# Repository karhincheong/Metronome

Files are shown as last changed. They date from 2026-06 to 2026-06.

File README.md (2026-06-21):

# Metronome

An electronic metronome powered by an ESP32-S3-WROOM Module, utilising a 160 x 128 LCD-TFT screen and a speaker

## Motivation

I find my phone too distracting when attending music class, hence I'm making this metronome on a separate device so that its simple and non-distracting

## BOM

### Components

| Item | Description | Quantity | Unit Price (USD) | Total Price (USD) | URL | MOQ |
| --- | --- | --- | --- | --- | --- | --- |
| Capacitors | 0805 22 uF | 1 | 0.0696 | 0.7 | https://www.lcsc.com/product-detail/C5674.html | 10  |
| | 0805 4.7 uF | 2 | 0.0267 | 0.53 | https://www.lcsc.com/product-detail/C1779.html | 20  |
| | 0805 10 uF | 1 | 0.0421 | 0.84 | https://www.lcsc.com/product-detail/C17024.html | 20  |
| | 0805 0.1 uF | 2 | 0.0061 | 0.15 | https://www.lcsc.com/product-detail/C476766.html | 25  |
| LEDs | 0805 YELLOW | 1 | 0.0118 | 0.59 | https://www.lcsc.com/product-detail/C20608785.html | 50  |
| | 0805 BLUE | 1 | 0.0078 | 0.78 | https://www.lcsc.com/product-detail/C19171391.html | 100 |
| | 0805 GREEN | 1 | 0.0222 | 0.67 | https://www.lcsc.com/product-detail/C84260.html | 30  |
| | 0805 RED | 1 | 0.007 | 0.7 | https://www.lcsc.com/product-detail/C965812.html | 100 |
| JST Connector | | 1 | 0.0393 | 0.79 | https://www.lcsc.com/product-detail/C173752.html | 20  |
| USB-C Receptacle | | 1 | 0.0877 | 0.44 | https://www.lcsc.com/product-detail/C2988369.html  | 5 |
| TFT-LCD | ST7735 160\*128  | 1 | 3.2069 | 3.21 | https://www.lcsc.com/product-detail/C5329585.html  | 1 |
| Speaker | | 1 | 0.818 | 0.82 | https://www.lcsc.com/product-detail/C530531.html | 1 |
| Resistors | 0805 2k | 2 | 0.0031 | 0.31 | https://www.lcsc.com/product-detail/C2907248.html  | 100 |
| | 0805 10k | 4 | 0.0031 | 0.31 | https://www.lcsc.com/product-detail/C2930231.html  | 100 |
| | 0805 5.1k | 2 | 0.0028 | 0.28 | https://www.lcsc.com/product-detail/C27834.html | 100 |
| | 0805 330k | 1 | 0.004 | 0.4 | https://www.lcsc.com/product-detail/C114528.html | 100 |
| | 0805 15k | 1 | 0.0033 | 0.33 | https://www.lcsc.com/product-detail/C2930170.html  | 100 |
| | 0805 470Ω | 3 | 0.003 | 0.3 | https://www.lcsc.com/product-detail/C2907267.html  | 100 |
| Rotary Encoders  | EC11 | 3 | 1.9069 | 5.72 | https://www.lcsc.com/product-detail/C470742.html | 1 |
| Slide Switch | SPST | 1 | 0.0541 | 0.54 | https://www.lcsc.com/product-detail/C7498220.html  | 10  |
| Push Buttons | 4.5 x 4.5 mm | 2 | 0.0109 | 0.55 | https://www.lcsc.com/product-detail/C52092029.html | 50  |
| | ⌀ 10 mm | 1 | 0.3832 | 0.38 | https://www.lcsc.com/product-detail/C268254.html | 1 |
| Thermistor | NTC 10k | 1 | 0.685 | 0.69 | https://www.lcsc.com/product-detail/C17376775.html | 1 |
| ESP32-S3-WROOM-1 | | 1 | 4.5417 | 4.54 | https://www.lcsc.com/product-detail/C2913197.html  | 1 |
| MCP73871 | | 1 | 4.5329 | 4.53 | https://www.lcsc.com/product-detail/C5121473.html  | 1 |
| AMS1117 | 3.3V Variant | 1 | 0.0424 | 0.04 | https://www.lcsc.com/product-detail/C347222.html | 1 |
| MAX98357A | | 1 | 1.3362 | 1.34 | https://www.lcsc.com/product-detail/C910544.html | 1 |
| USBLC6-2SC6 | | 1 | 0.164 | 0.82 | https://www.lcsc.com/product-detail/C7519.html | 5 |
| Battery | 3.7V LiPO 300mAh | 1 | 0.79 | 0.79 | https://item.szlcsc.com/mro/419942.html | 1 |
| | | | | | | |
| TOTAL | | | | 32.09 | | |

### Other Costs Incurred

| Item | Description | Price |
| --- | --- | ----- |
| PCB Printing | JLCPCB | 2.00  |
| Shipping | UPS Express Saver | 9.24  |

## Assembly Instructions

| Folder | Description |
| --- | --- |
| `kicad/` | KiCAD files |
| `3d/` | 3D files for the case and the PCB |
| `src/` | Source Code for firmware |
| `production/` | Files for manufacturers |

1. Solder the components by hand onto the PCB. You may opt for PCBA for some of the components but it's expensive.
2. Flash firmware in `src/main` onto the PCB by connecting your computer to the USB-C on the PCB. You may also have to press down on BOOT and RESET for it to enter serial download mode
3. 3D Print the case of the the PCB.
4. Install the PCB into the case by screwing the PCB down using 4 M2 screws onto the 4 holes.

## Schematic Diagram

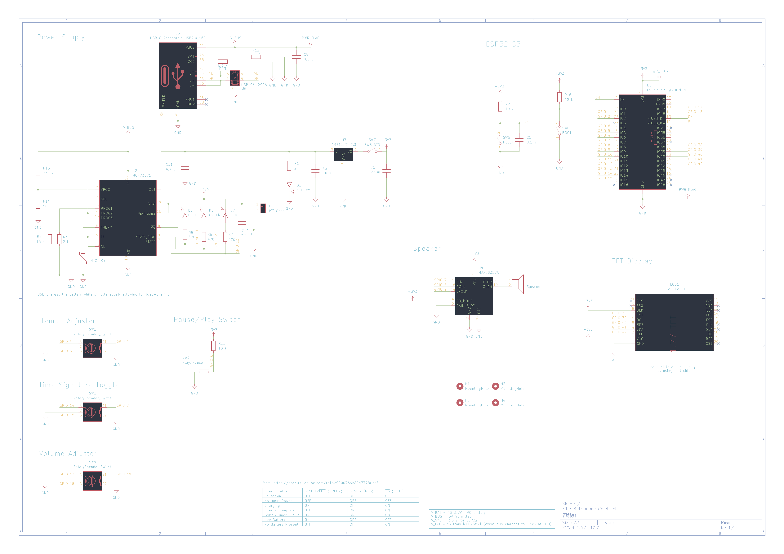
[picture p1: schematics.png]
Schematics


For clearer version, please refer `schematics.pdf`, or maybe you're trying to attract bugs ...

## PCB Layout

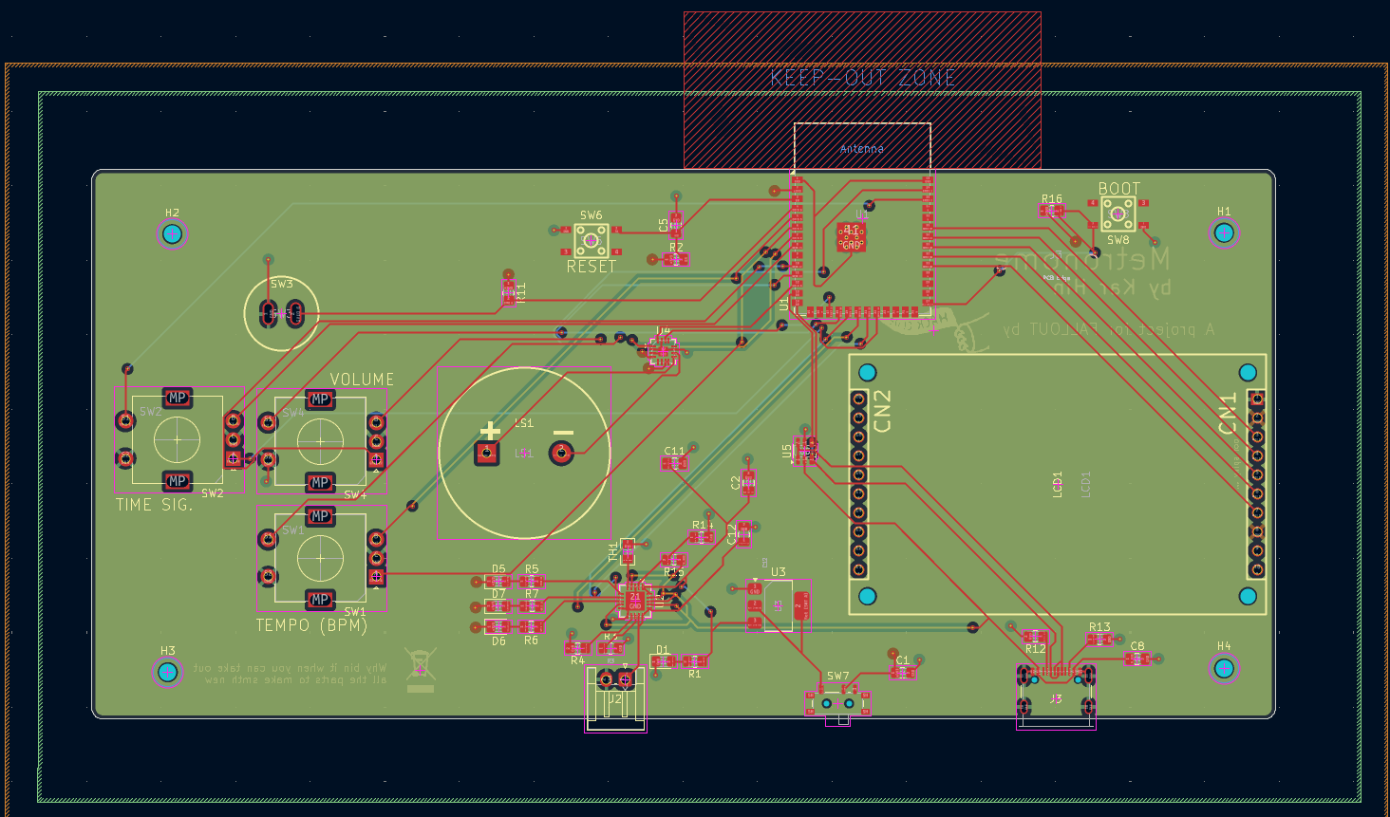
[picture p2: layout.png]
Layout


## PCB Render

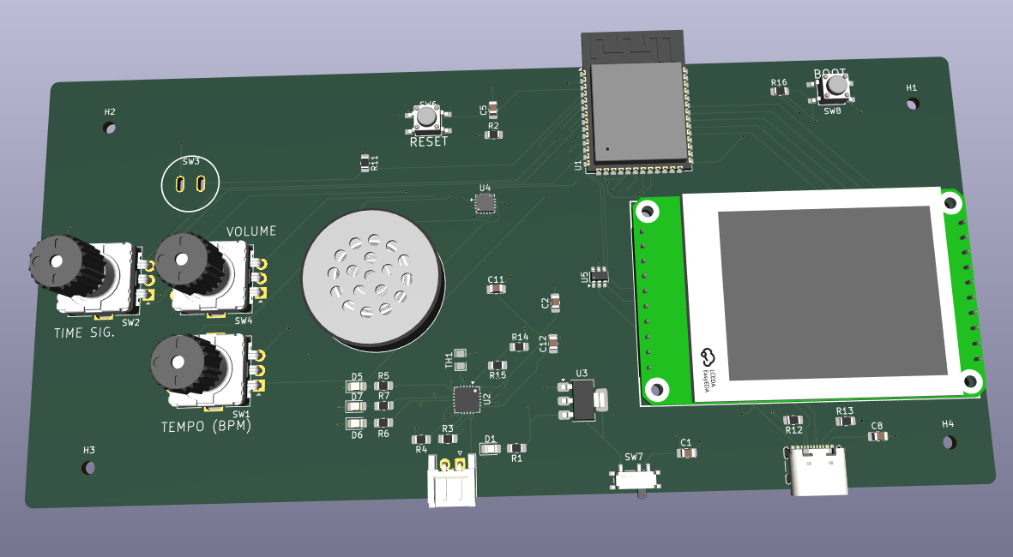
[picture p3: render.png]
PCB Render


You may refer to `3d/pcb3d.step` but note that there will not be any silkscreen or solder mask on it

## Case

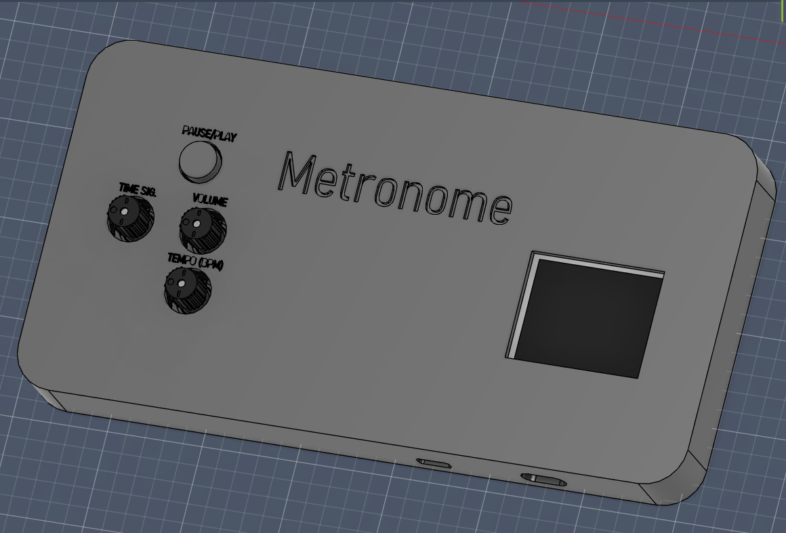
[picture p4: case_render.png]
Case Render


Refer to `3d/metronomecase.step` or `3d/metronomecase.f3d` if you use Autodesk Fusion

## Project Zine

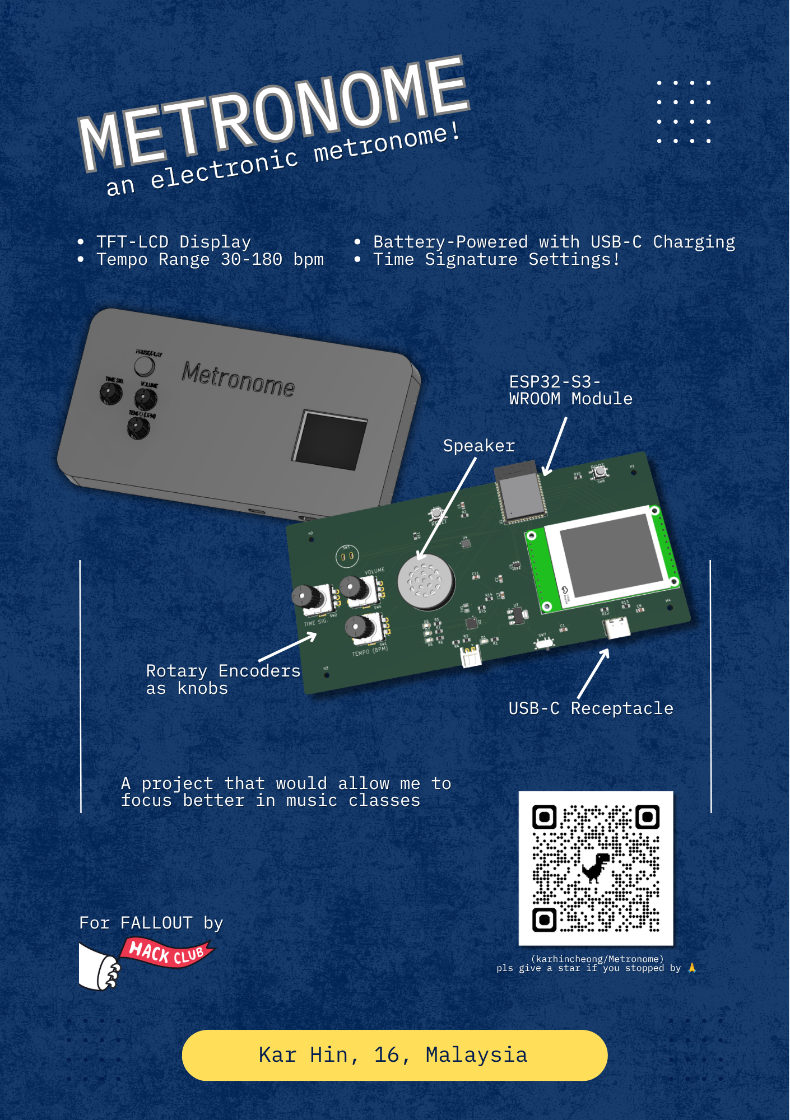
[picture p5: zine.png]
Zine


Uncompressed version at `zine.pdf`

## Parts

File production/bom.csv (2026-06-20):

Designator | Footprint | Quantity | Value | LCSC Part #
C1 | 0805 | 1 | 22 uF
C11, C12 | 0805 | 2 | 4.7 uF
C2 | 0805 | 1 | 10 uF
C5, C8 | 0805 | 2 | 0.1 uF
D1 | 0805 | 1 | YELLOW
D5 | 0805 | 1 | BLUE
D6 | 0805 | 1 | GREEN
D7 | 0805 | 1 | RED
J2 | JST_EH_S2B-EH_1x02_P2.50mm_Horizontal | 1 | JST Connector
J3 | USB_C_Receptacle_GCT_USB4105-xx-A_16P_TopMnt_Horizontal | 1 | USB_C_Receptacle_USB2.0_16P
LCD1 | LCD-TH_L56.0-W35.0-P2.54_HS180S10B | 1 | HS180S10B | C5329585
LS1 | SPK-TH_BD23.0-P10.00-D0.8-L-RD | 1 | Speaker
R1, R3 | 0805 | 2 | 2 k
R11, R14, R16, R2 | 0805 | 4 | 10 k
R12, R13 | 0805 | 2 | 5.1 k
R15 | 0805 | 1 | 330 k
R4 | 0805 | 1 | 15 k
R5, R6, R7 | 0805 | 3 | 470
SW1, SW2, SW4 | RotaryEncoder_Alps_EC11E-Switch_Vertical_H20mm | 3 | RotaryEncoder_Switch
SW3 | CONN-TH_PB-05B-R | 1 | Play/Pause
SW6 | SW-SMD_4P-L4.5-W4.5-P3.00-LS7.0_TS-1009S-03826 | 1 | RESET
SW7 | SW_SPDT_Shouhan_MSK12C02 | 1 | PWR_BTN
SW8 | SW-SMD_4P-L4.5-W4.5-P3.00-LS7.0_TS-1009S-03826 | 1 | BOOT
TH1 | R0805 | 1 | NTC 10k
U1 | ESP32-S3-WROOM-1 | 1 | ESP32-S3-WROOM-1
U2 | QFN-20-1EP_4x4mm_P0.5mm_EP2.5x2.5mm | 1 | MCP73871
U3 | SOT-223-3_TabPin2 | 1 | AMS1117-3.3
U4 | TQFN-16-1EP_3x3mm_P0.5mm_EP1.23x1.23mm | 1 | MAX98357A
U5 | SOT-23-6 | 1 | USBLC6-2SC6

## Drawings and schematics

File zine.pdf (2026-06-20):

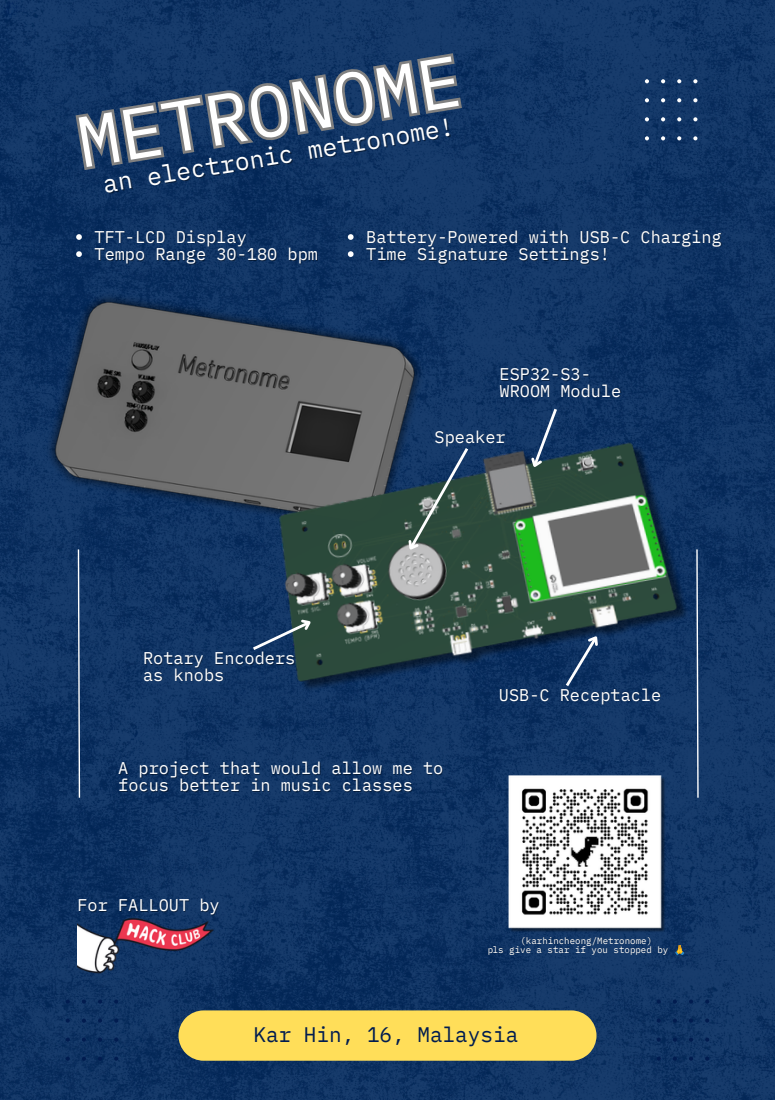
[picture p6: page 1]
Rotary Encoders as knobs; Speaker; USB-C Receptacle; ESP32-S3- WROOM Module

METRONOME METRONOME METRONOME

an electronic metronome!

TFT-LCD Display
Tempo Range 30-180 bpm

Battery-Powered with USB-C Charging
Time Signature Settings!

A project that would allow me to
focus better in music classes

For FALLOUT by

(karhincheong/Metronome)
pls give a star if you stopped by 🙏

Kar Hin, 16, Malaysia

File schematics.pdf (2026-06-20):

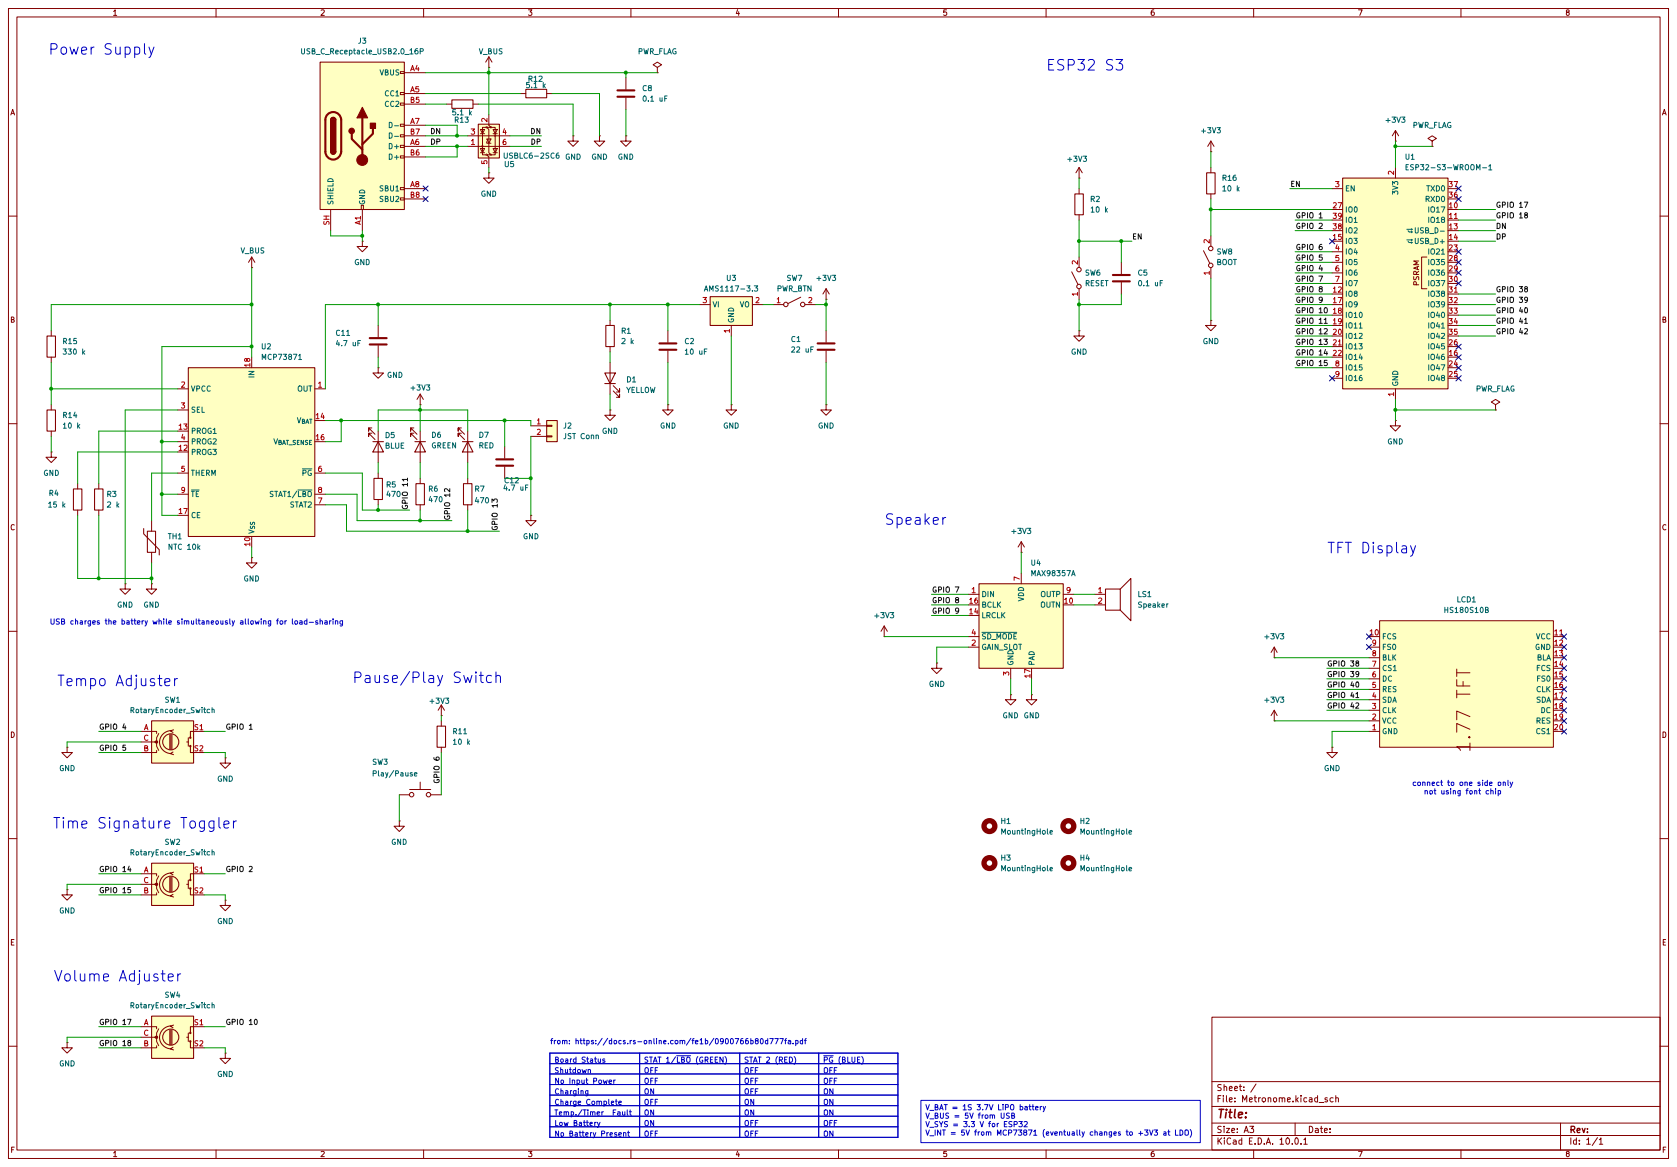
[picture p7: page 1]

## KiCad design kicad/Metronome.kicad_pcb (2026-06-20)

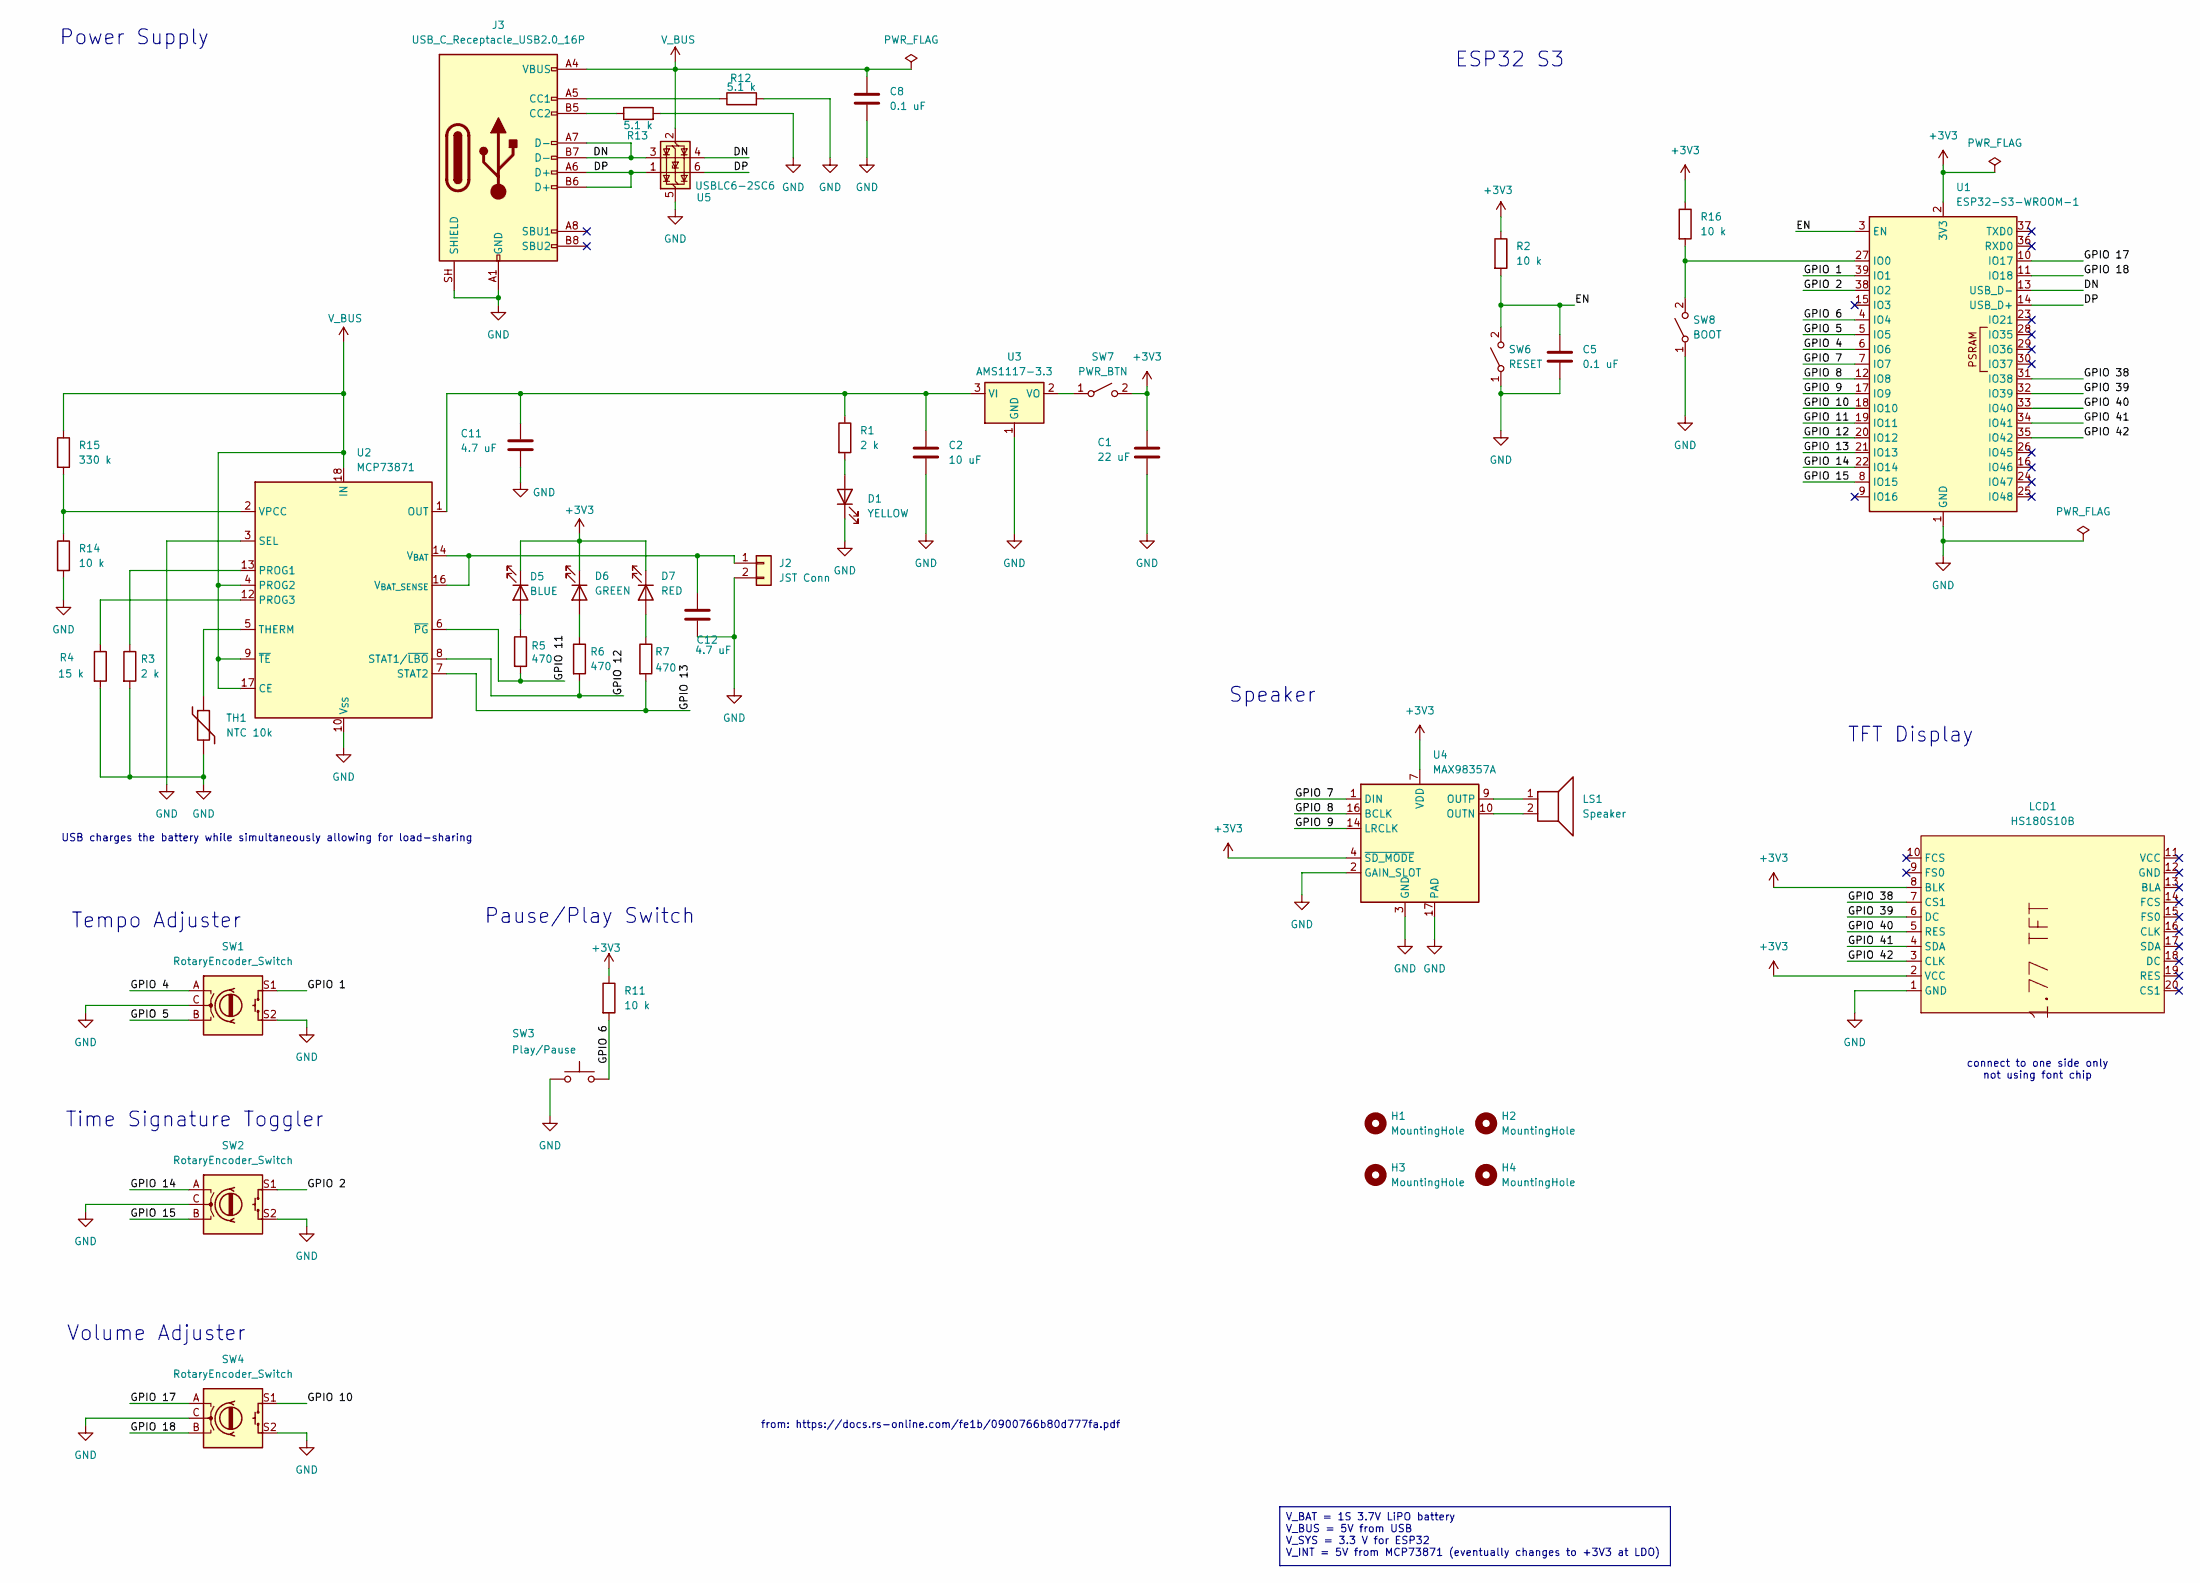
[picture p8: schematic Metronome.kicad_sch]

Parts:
C1: 22 uF; C_0805_2012Metric_Pad1.18x1.45mm_HandSolder
C2: 10 uF; C_0805_2012Metric_Pad1.18x1.45mm_HandSolder
C5, C8: 0.1 uF; C_0805_2012Metric_Pad1.18x1.45mm_HandSolder
C11, C12: 4.7 uF; C_0805_2012Metric_Pad1.18x1.45mm_HandSolder
D1: YELLOW; LED_0805_2012Metric_Pad1.15x1.40mm_HandSolder
D5: BLUE; LED_0805_2012Metric_Pad1.15x1.40mm_HandSolder
D6: GREEN; LED_0805_2012Metric_Pad1.15x1.40mm_HandSolder
D7: RED; LED_0805_2012Metric_Pad1.15x1.40mm_HandSolder
H1, H2, H3, H4: MountingHole; MountingHole_2.2mm_M2_DIN965
J2: JST Conn; JST_EH_S2B-EH_1x02_P2.50mm_Horizontal
J3: USB_C_Receptacle_USB2.0_16P; USB_C_Receptacle_GCT_USB4105-xx-A_16P_TopMnt_Horizontal
LCD1: HS180S10B; LCD-TH_L56.0-W35.0-P2.54_HS180S10B; MPN HS180S10B; LCSC Part C5329585
LS1: Speaker; SPK-TH_BD23.0-P10.00-D0.8-L-RD
R1, R3: 2 k; R_0805_2012Metric_Pad1.20x1.40mm_HandSolder
R2, R11, R14, R16: 10 k; R_0805_2012Metric_Pad1.20x1.40mm_HandSolder
R4: 15 k; R_0805_2012Metric_Pad1.20x1.40mm_HandSolder
R5, R6, R7: 470; R_0805_2012Metric_Pad1.20x1.40mm_HandSolder
R12, R13: 5.1 k; R_0805_2012Metric_Pad1.20x1.40mm_HandSolder
R15: 330 k; R_0805_2012Metric_Pad1.20x1.40mm_HandSolder
SW1, SW2, SW4: RotaryEncoder_Switch; RotaryEncoder_Alps_EC11E-Switch_Vertical_H20mm
SW3: Play/Pause; CONN-TH_PB-05B-R
SW6: RESET; SW-SMD_4P-L4.5-W4.5-P3.00-LS7.0_TS-1009S-03826
SW7: PWR_BTN; SW_SPDT_Shouhan_MSK12C02
SW8: BOOT; SW-SMD_4P-L4.5-W4.5-P3.00-LS7.0_TS-1009S-03826
TH1: NTC 10k; R0805
U1: ESP32-S3-WROOM-1
U2: MCP73871; QFN-20-1EP_4x4mm_P0.5mm_EP2.5x2.5mm
U3: AMS1117-3.3; SOT-223-3_TabPin2
U4: MAX98357A; TQFN-16-1EP_3x3mm_P0.5mm_EP1.23x1.23mm
U5: USBLC6-2SC6; SOT-23-6

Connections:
+3V3: C1.1, D5.1 (K), D6.1 (K), D7.1 (K), LCD1.2 (VCC), LCD1.8 (BLK), R2.1, R11.1, R16.1, SW7.2 (B), U1.2 (3V3), U4.4 (~SD_MODE), U4.7 (VDD), U4.8 (VDD)
/DN: J3.A7 (D-), J3.B7 (D-), U1.13 (USB_D-), U5.3 (I/O2), U5.4 (I/O2)
/DP: J3.A6 (D+), J3.B6 (D+), U1.14 (USB_D+), U5.1 (I/O1), U5.6 (I/O1)
/EN: C5.1, R2.2, SW6.2 (B), U1.3 (EN)
/GPIO 1: SW1.S1, U1.39 (IO1)
/GPIO 2: SW2.S1, U1.38 (IO2)
/GPIO 4: SW1.A, U1.6 (IO6)
/GPIO 5: SW1.B, U1.5 (IO5)
/GPIO 6: R11.2, SW3.2, U1.4 (IO4)
/GPIO 7: U1.7 (IO7), U4.1 (DIN)
/GPIO 8: U1.12 (IO8), U4.16 (BCLK)
/GPIO 9: U1.17 (IO9), U4.14 (LRCLK)
/GPIO 10: SW4.S1, U1.18 (IO10)
/GPIO 11: R5.2, U1.19 (IO11), U2.6 (~PG)
/GPIO 12: R6.2, U1.20 (IO12), U2.8 (STAT1/~LBO)
/GPIO 13: R7.2, U1.21 (IO13), U2.7 (STAT2)
/GPIO 14: SW2.A, U1.22 (IO14)
/GPIO 15: SW2.B, U1.8 (IO15)
/GPIO 17: SW4.A, U1.10 (IO17)
/GPIO 18: SW4.B, U1.11 (IO18)
/GPIO 38: LCD1.7 (CS1), U1.31 (IO38)
/GPIO 39: LCD1.6 (DC), U1.32 (IO39)
/GPIO 40: LCD1.5 (RES), U1.33 (IO40)
/GPIO 41: LCD1.4 (SDA), U1.34 (IO41)
/GPIO 42: LCD1.3 (CLK), U1.35 (IO42)
GND: C1.2, C2.2, C5.2, C8.2, C11.2, C12.2, D1.1 (K), J2.2, J3.A1 (GND), J3.A12 (GND), J3.B1 (GND), J3.B12 (GND), J3.SH (SHIELD), LCD1.1 (GND), R3.2, R4.2, R12.2, R13.2, R14.2, SW1.C, SW1.S2, SW2.C, SW2.S2, SW3.1, SW4.C, SW4.S2, SW6.1 (A), SW8.1 (A), TH1.2, U1.1 (GND), U1.40 (GND), U1.41 (GND), U2.3 (SEL), U2.10 (V_{SS}), U2.11 (V_{SS}), U2.21 (V_{SS}), U3.1 (GND), U4.2 (GAIN_SLOT), U4.3 (GND), U4.11 (GND), U4.15 (GND), U4.17 (PAD), U5.5 (VBUS)
unnamed: D1.2 (A), R1.2
unnamed: D5.2 (A), R5.1
unnamed: D6.2 (A), R6.1
unnamed: D7.2 (A), R7.1
unnamed: C12.1, J2.1, U2.14 (V_{BAT}), U2.15 (V_{BAT}), U2.16 (V_{BAT_SENSE})
unnamed: J3.A5 (CC1), R12.1
unnamed: J3.B5 (CC2), R13.1
unnamed: SW7.1 (A), U3.2 (VO)
unnamed: R16.2, SW8.2 (B), U1.27 (IO0)
unnamed: R3.1, U2.13 (PROG1)
unnamed: R4.1, U2.12 (PROG3)
unnamed: TH1.1, U2.5 (THERM)
unnamed: R14.1, R15.2, U2.2 (VPCC)
unnamed: C2.1, C11.1, R1.1, U2.1 (OUT), U2.20 (OUT), U3.3 (VI)
unnamed: LS1.2, U4.10 (OUTN)
unnamed: LS1.1, U4.9 (OUTP)
V_BUS: C8.1, J3.A4 (VBUS), J3.A9 (VBUS), J3.B4 (VBUS), J3.B9 (VBUS), R15.1, U2.4 (PROG2), U2.9 (~TE), U2.17 (CE), U2.18 (IN), U2.19 (IN), U5.2 (GND)

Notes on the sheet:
Power Supply
ESP32 S3
TFT Display
USB charges the battery while simultaneously allowing for load-sharing
Tempo Adjuster
Speaker
Time Signature Toggler
connect to one side only not using font chip
Volume Adjuster
from: https://docs.rs-online.com/fe1b/0900766b80d777fa.pdf
Pause/Play Switch
V_BAT = 1S 3.7V LiPO battery V_BUS = 5V from USB V_SYS = 3.3 V for ESP32 V_INT = 5V from MCP73871 (eventually changes to +3V3 at LDO)

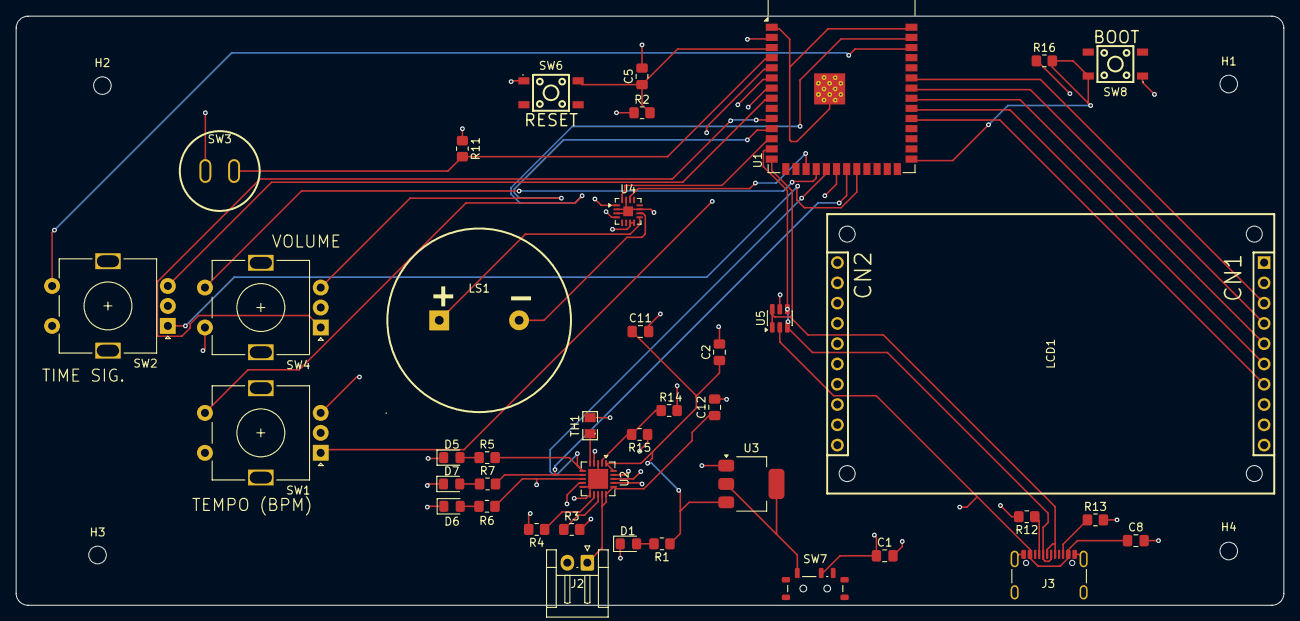
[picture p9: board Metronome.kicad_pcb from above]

Board: 4 copper layers, 158.8 x 73.8 mm, 44 parts (0 on the bottom side), 43 nets.

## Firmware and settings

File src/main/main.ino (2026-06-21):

#include <AudioLogger.h>
#include <AudioTools.h>
#include <AudioToolsConfig.h>

#include <Adafruit_ST7735.h>
#include <Adafruit_GFX.h>
#include <ESP32RotaryEncoder.h>
#include <SPI.h>
#include <driver/i2s.h>
#include <Audio.h>
#include "display.ino"
#include "speaker.ino"
#include "config.h"

/*
from example code
connecting Rotary encoder

Rotary encoder side    MICROCONTROLLER side  
-------------------    ---------------------------------------------------------------------
CLK (A pin)            any microcontroler intput pin with interrupt -> in this example pin 32
DT (B pin)             any microcontroler intput pin with interrupt -> in this example pin 21
SW (button pin)        any microcontroler intput pin with interrupt -> in this example pin 25
GND - to microcontroler GND
VCC                    microcontroler VCC (then set ROTARY_ENCODER_VCC_PIN -1) 

***OR in case VCC pin is not free you can cheat and connect:***
VCC                    any microcontroler output pin - but set also ROTARY_ENCODER_VCC_PIN 25 
                        in this example pin 25

*/



int tempo = 60;
int timesigsel = 0;
int volumesel = 0;

struct timesig {
	int uppper;
	int lower;
};

const timesig SIGS arr[4] = {{1,4}, {2,4}, {3,4}, {4,4}};
const uint8_t SIG_COUNT = sizeof(SIGS) / sizeof(SIGS[0]);

RotaryEncoder re_tempo(TEMPO_A_PIN, TEMPO_B_PIN, TEMPO_BUTTON_PIN);
RotaryEncoder re_timesig(TIMESIG_A_PIN, TIMESIG_B_PIN, TIMESIG_BUTTON_PIN);
RotaryEncoder re_volume(VOLUME_A_PIN, VOLUME_B_PIN, VOLUME_BUTTON_PIN);

Adafruit_ST7735 tft = Adafruit_ST7735(TFT_CS, TFT_DC, TFT_RST);

static void handlePlayPause(){
	play = digitalRead(PAUSEPLAY);
}

void storetempovalue(long value) {
	tempo = value;
	g_uiDirty = true;
}

void storetimesigvalue(long value) {
	timesigsel = value;
	g_uiDirty = true;
}

void storevolumevalue(long value) {
	timesig = value;
	g_uiDirty = true;
}

void setupRotaryEncoders(){
	re_tempo.setBoundaries(30, 180, false);          // 30..250 BPM, no wrap
  re_tempo.onTurned(&storetempovalue);
  re_tempo.setEncoderValue(g_tempo);
  re_tempo.begin();

  re_timesig.setBoundaries(0, SIG_COUNT - 1, true); // wrap around the list
  re_timesig.onTurned(&storetimesigvalue));
  re_timesig.setEncoderValue(g_sigIndex);
  re_timesig.begin();

  re_volume.setBoundaries(0, 10, false);            // 0..10
  re_volume.onTurned(&storevolumevalue);
  re_volume.setEncoderValue(g_volume);
  re_volume.begin();
}

void setup() {
	// put your setup code here, to run once:
	Serial.begin(115200);

	setupRotaryEncoders();
	setupDisplay();
	setupSpeaker();
	volatile bool play = true;
	tft.initR(INITR_GREENTAB);

	// Setup I2S
	audio.setPinout(SPEAKER_BCLK, SPEAKER_LRCLK, SPEAKER_DOUT);

	// Set Volume
	audio.setVolume(5);



	// Open music file
	
	// sine wave modulation for metronome tock
}

void loop() {
	// put your main code here, to run repeatedly:
	double time_between_beat = 60000/tempo;

	if (g_uiDirty) {
    g_uiDirty = false;
    if (g_currentBeat >= SIGS[g_sigIndex].num) g_currentBeat = 0;
    redrawControls();
  }
	 if (g_running) {
    // Tempo is quarter-note BPM. Scale by the lower number so that, if you
    // later add e.g. x/8 signatures, an eighth-note beat is half as long.
    unsigned long interval =
        (60000UL * 4UL) / ((unsigned long)g_tempo * SIGS[g_sigIndex].den);

    unsigned long now = millis();
    if (now - g_lastBeat >= interval) {
      g_lastBeat += interval;                       // keep phase locked...
      if (now - g_lastBeat >= interval) {           // ...but resync if we
        g_lastBeat = now;                           //    fell badly behind
      }

      int  total  = SIGS[g_sigIndex].num;
      bool accent = (g_currentBeat == 0);

      drawBeats(g_currentBeat, total);              // fast SPI update first
      playTock(accent, g_volume / 10.0f);           // then the click

      g_currentBeat = (g_currentBeat + 1) % total;
    }
  } else {
    // Parked on the downbeat while paused.
    g_currentBeat = 0;
    g_lastBeat    = millis();
  }
}


}

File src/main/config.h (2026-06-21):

#define TEMPO_A_PIN 4
#define TEMPO_B_PIN 5
#define TEMPO_BUTTON_PIN 1

#define TIMESIG_A_PIN 14
#define TIMESIG_B_PIN 15
#define TIMESIG_BUTTON_PIN 2

#define VOLUME_A_PIN 17
#define VOLUME_A_PIN 18
#define VOLUME_BUTTON_PIN 10

#define TFT_CS 38
#define TFT_DC 39
#define TFT_RST 40
#define TFT_SDA 41
#define TFT_CLK 42

#define PAUSEPLAY 6

#define SPEAKER_DOUT 7  //DIN on MAX39857A
#define SPEAKER_BCLK 8
#define SPEAKER_LRCLK 9

#define SAMPLE_RATE 44100
#define I2S_NUM I2S_NUM_0

#define SAMPLE_RATE   44100
#define FREQ   1000
